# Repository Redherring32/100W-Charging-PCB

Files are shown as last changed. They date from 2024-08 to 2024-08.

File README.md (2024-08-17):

# 100W-Charging-PCB
100W USB C PD Lithium Ion charging PCB based on the TPS25750D and BQ25713

This PCB is spec'd for 20V 5A USB C PD charging of a 1S configuration of Lithium Ion cells, it is suitable for dropping into a variety of battery powered projects that may be a bit more power hungry or where faster charging may be desired.
Within this repository you can find everything to build this PCB, as well as source design files for it should you need to repurpose it for a different form factor or design.

# PCB SPECS:
* 4 layers
* 38.5x38.5mm
* filled vias (VIPPO) is recommended for assembly reasons due to via in pad

Render

## LICENSE:
Licensed under
the TAPR Open hardware license (www.tapr.org/OHL)

©Redherring32 2024

## DISCLAIMER:

Lithium Ion Batteries are DANGEROUS, they should not be handled if you do not know what you are doing.
I offer this with no warranty, express or implied, and I am NOT responsible for anything that may happen as a result of misuse of this PCB.
You have been warned.

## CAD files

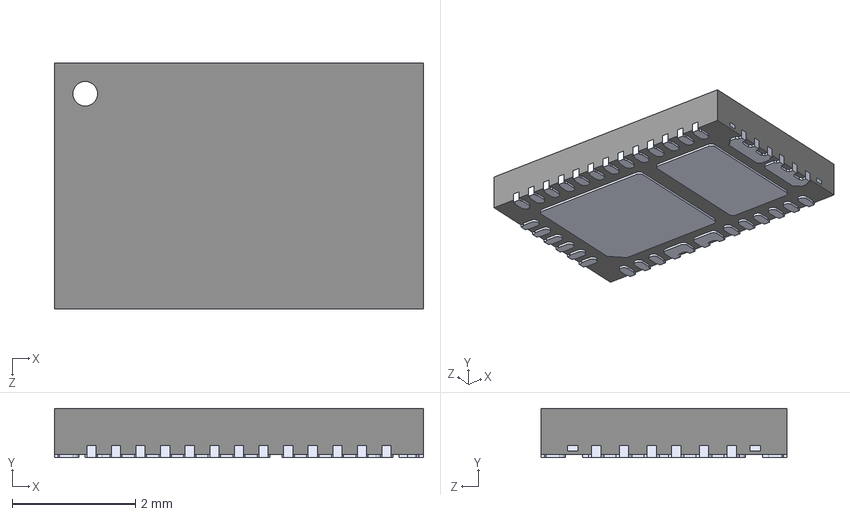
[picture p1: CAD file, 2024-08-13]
3D/TPS25750DRJKR.STEP
6.00 x 0.8 x 4.00 mm

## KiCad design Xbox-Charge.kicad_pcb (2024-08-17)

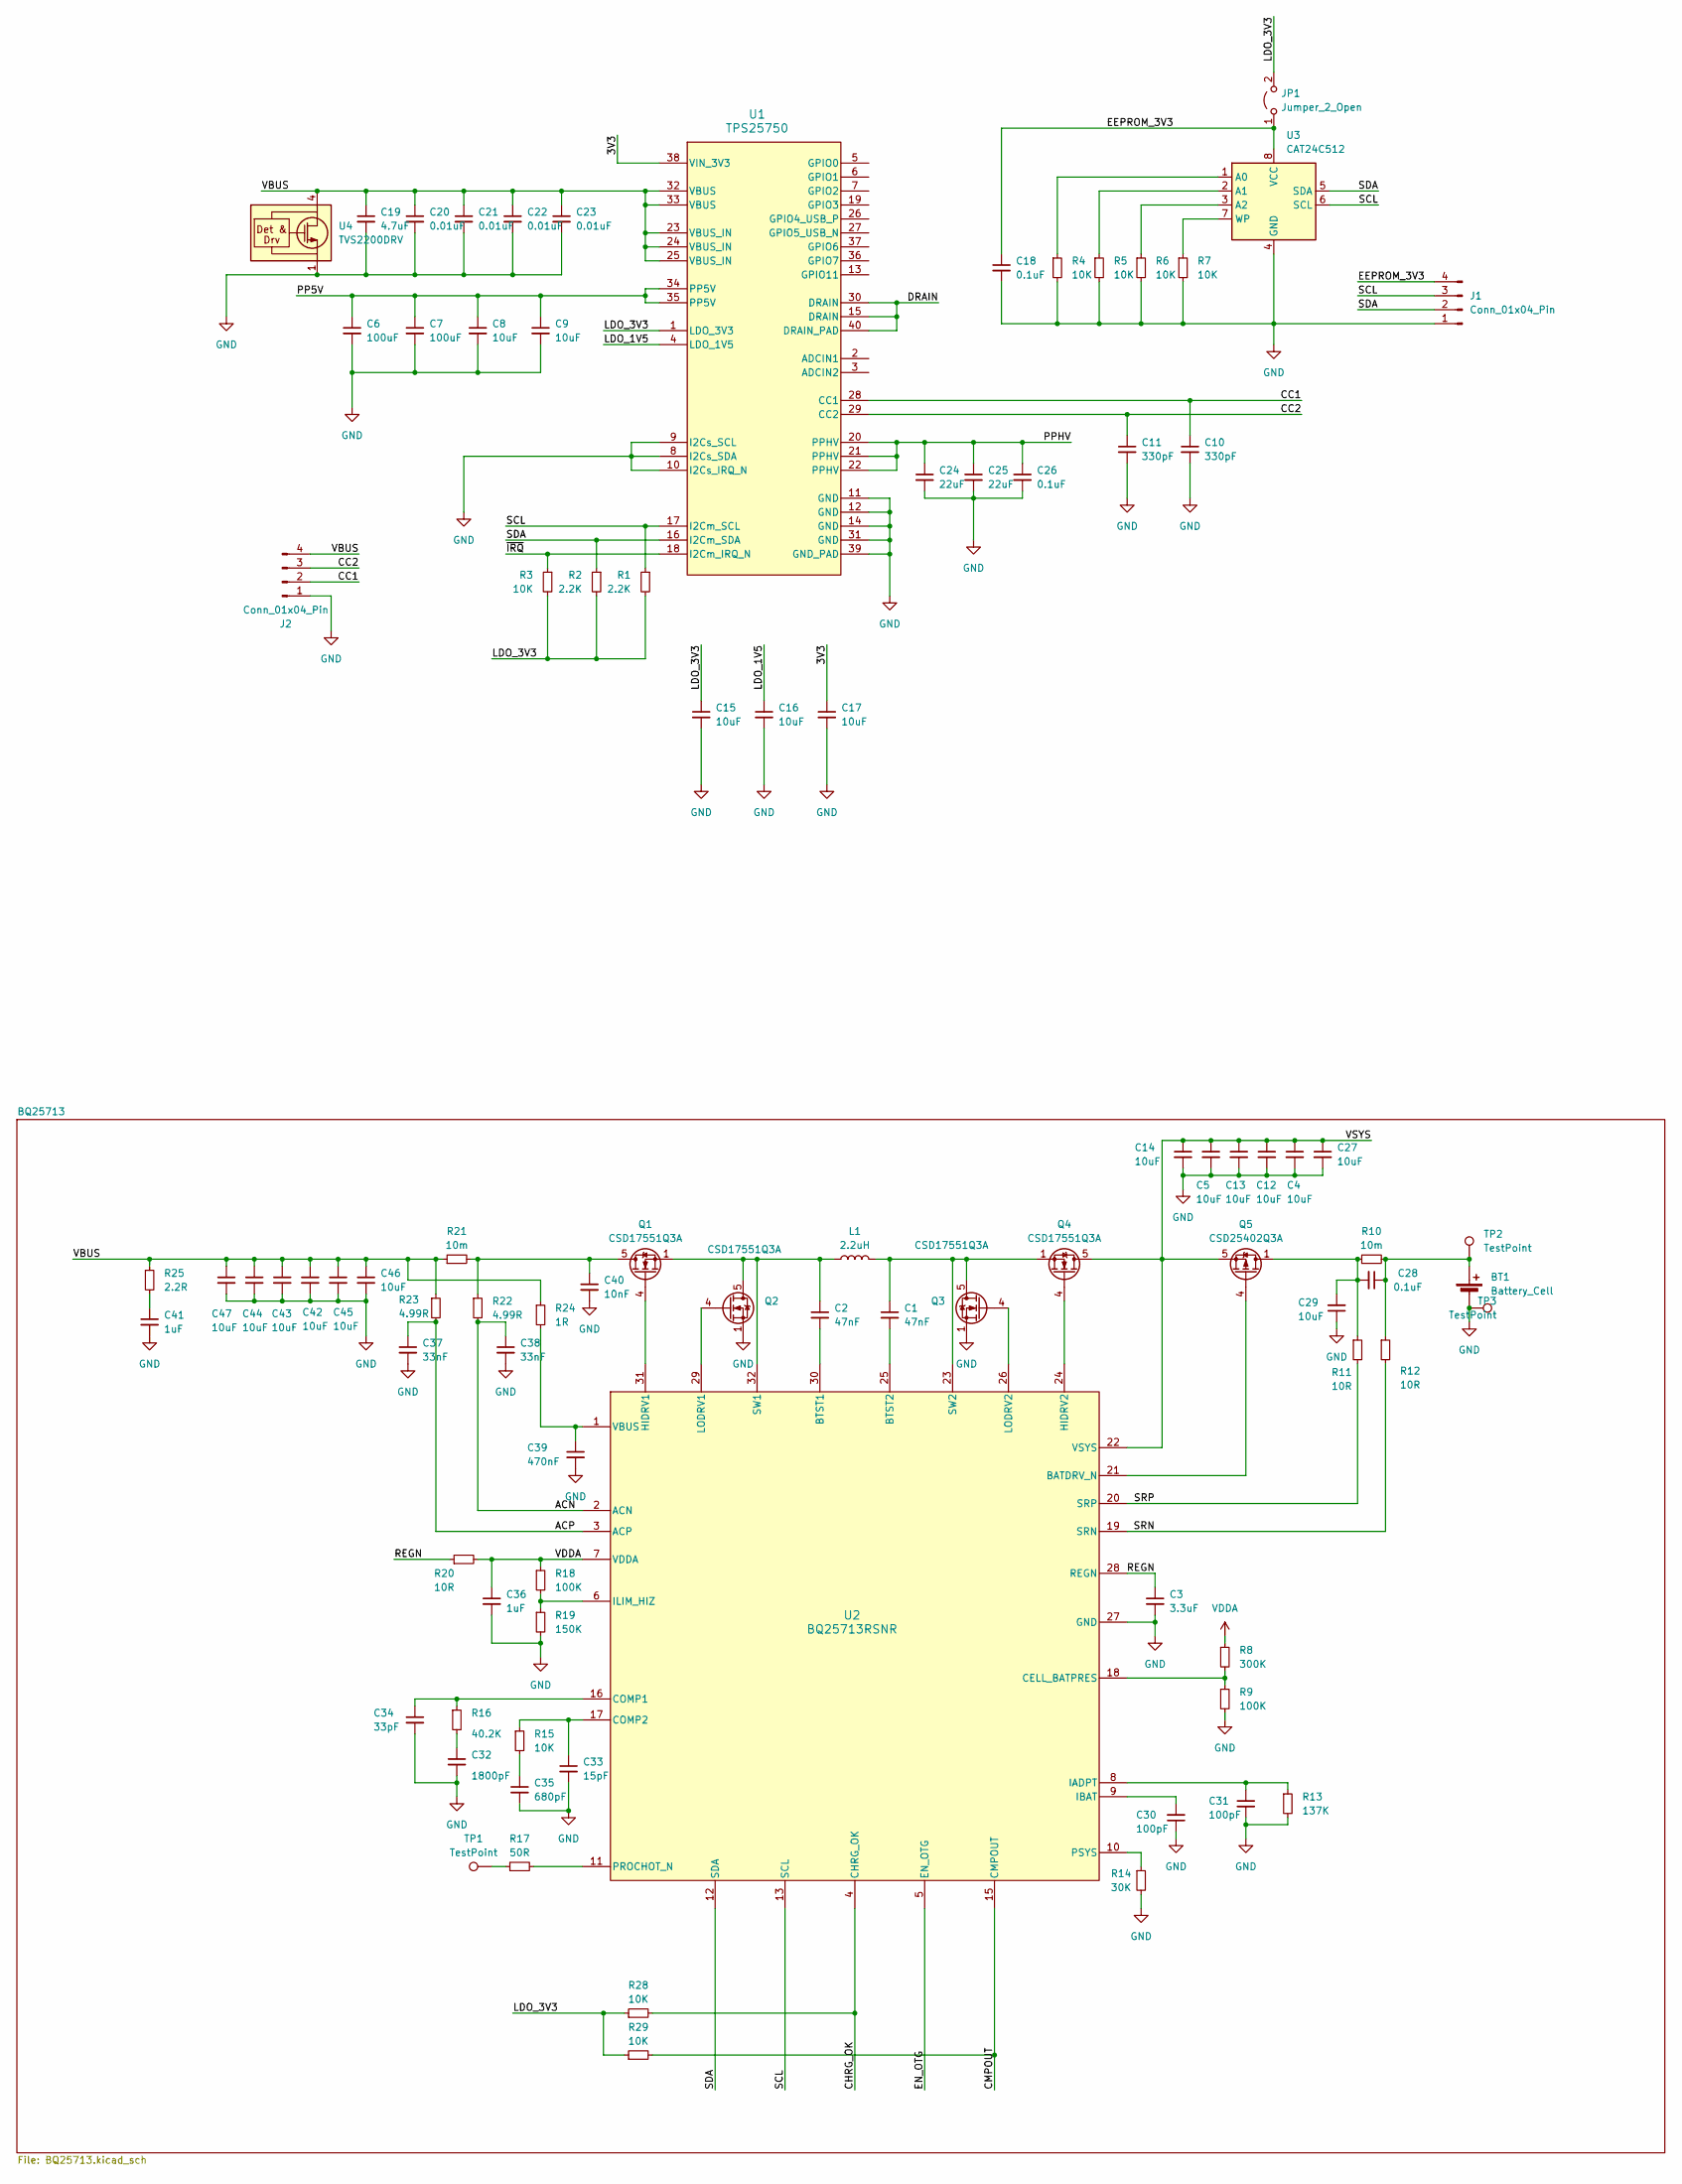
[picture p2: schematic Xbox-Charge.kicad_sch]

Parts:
BT1: Battery_Cell
C1, C2: 47nF; C_0603_1608Metric
C3: 3.3uF; C_0603_1608Metric
C4, C5, C12, C13, C14, C27, C42, C43, C44, C45, C46, C47: 10uF; C_0805_2012Metric
C6, C7: 100uF; C_1210_3225Metric
C8, C9, C29: 10uF; C_0603_1608Metric
C10, C11: 330pF; C_0201_0603Metric
C15, C16, C17: 10uF; C_0402_1005Metric
C18, C26: 0.1uF; C_0402_1005Metric
C19: 4.7uF; C_0805_2012Metric
C20, C21, C22, C23: 0.01uF; C_0402_1005Metric
C24, C25: 22uF; C_0805_2012Metric
C28: 0.1uF; C_0603_1608Metric
C30, C31: 100pF; C_0603_1608Metric
C32: 1800pF; C_0402_1005Metric
C33: 15pF; C_0402_1005Metric
C34: 33pF; C_0402_1005Metric
C35: 680pF; C_0402_1005Metric
C36: 1uF; C_0402_1005Metric
C37, C38: 33nF; C_0603_1608Metric
C39: 470nF; C_0805_2012Metric
C40: 10nF; C_0402_1005Metric
C41: 1uF
J1: Conn_01x04_Pin; PROG
J2: Conn_01x04_Pin; VBUS PADS
JP1: Jumper_2_Open; SolderJumper-2_P1.3mm_Open_RoundedPad1.0x1.5mm
L1: 2.2uH; L_Chilisin_BMRx00060630
Q1, Q2, Q3, Q4: CSD17551Q3A; VSON-8_3.3x3.3mm_P0.65mm_NexFET
Q5: CSD25402Q3A; VSON-8_3.3x3.3mm_P0.65mm_NexFET
R1, R2: 2.2K; R_0402_1005Metric
R3, R4, R5, R6, R7, R15, R28, R29: 10K; R_0402_1005Metric
R8: 300K; R_0402_1005Metric
R9, R18: 100K; R_0402_1005Metric
R10, R21: 10m; R_1206_3216Metric
R11, R12: 10R; R_0603_1608Metric
R13: 137K; R_0603_1608Metric
R14: 30K; R_0603_1608Metric
R16: 40.2K; R_0402_1005Metric
R17: 50R
R19: 150K; R_0402_1005Metric
R20: 10R; R_0402_1005Metric
R22, R23: 4.99R; R_0603_1608Metric
R24: 1R; R_0805_2012Metric
R25: 2.2R
TP1: TestPoint
TP2, TP3: TestPoint; TestPoint_Pad_3.0x3.0mm
U1: TPS25750; TPS25750D
U2: BQ25713RSNR; Texas_RSN_WQFN-32-1EP_4x4mm_P0.4mm_EP2.8x2.8mm
U3: CAT24C512; SOIC-8_3.9x4.9mm_P1.27mm
U4: TVS2200DRV; WSON-6-1EP_2x2mm_P0.65mm_EP1x1.6mm

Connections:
/3V3: C17.1, U1.38 (VIN_3V3)
/ACN: C38.1, R22.2, U2.2 (ACN)
/ACP: C37.1, R23.2, U2.3 (ACP)
/CC1: C10.1, J2.2, U1.28 (CC1)
/CC2: C11.1, J2.3, U1.29 (CC2)
/CHRG_OK: R28.2, U2.4 (CHRG_OK)
/CMPOUT: R29.2, U2.15 (CMPOUT)
/DRAIN: U1.15 (DRAIN), U1.30 (DRAIN), U1.40 (DRAIN_PAD)
/EEPROM_3V3: C18.1, J1.4, JP1.1 (A), U3.8 (VCC)
/EN_OTG: U2.5 (EN_OTG)
/LDO_1V5: C16.1, U1.4 (LDO_1V5)
/LDO_3V3: C15.1, JP1.2 (B), R1.2, R2.2, R3.2, R28.1, R29.1, U1.1 (LDO_3V3)
/PP5V: C6.1, C7.1, C8.1, C9.1, U1.34 (PP5V), U1.35 (PP5V)
/PPHV: C24.1, C25.1, C26.1, U1.20 (PPHV), U1.21 (PPHV), U1.22 (PPHV)
/REGN: C3.1, R20.1, U2.28 (REGN)
/SCL: J1.3, R1.1, U1.17 (I2Cm_SCL), U2.13 (SCL), U3.6 (SCL)
/SDA: J1.2, R2.1, U1.16 (I2Cm_SDA), U2.12 (SDA), U3.5 (SDA)
/SRN: R12.2, U2.19 (SRN)
/SRP: R11.2, U2.20 (SRP)
/VBUS: C19.1, C20.1, C21.1, C22.1, C23.1, C42.1, C43.1, C44.1, C45.1, C46.1, C47.1, J2.4, R21.1, R23.1, R24.1, R25.1, U1.23 (VBUS_IN), U1.24 (VBUS_IN), U1.25 (VBUS_IN), U1.32 (VBUS), U1.33 (VBUS), U4.4 (IN), U4.5 (IN), U4.6 (IN)
/VSYS: C4.1, C5.1, C12.1, C13.1, C14.1, C27.1, Q4.5 (D), Q5.5 (S), U2.22 (VSYS)
/~IRQ: R3.1, U1.18 (I2Cm_IRQ_N)
GND: BT1.2 (-), C3.2, C4.2, C5.2, C6.2, C7.2, C8.2, C9.2, C10.2, C11.2, C12.2, C13.2, C14.2, C15.2, C16.2, C17.2, C18.2, C19.2, C20.2, C21.2, C22.2, C23.2, C24.2, C25.2, C26.2, C27.2, C29.1, C30.1, C31.2, C32.2, C33.2, C34.2, C35.2, C36.2, C37.2, C38.2, C39.2, C40.2, C41.2, C42.2, C43.2, C44.2, C45.2, C46.2, C47.2, J1.1, J2.1, Q2.1 (S), Q2.2 (S), Q2.3 (S), Q3.1 (S), Q3.2 (S), Q3.3 (S), R4.2, R5.2, R6.2, R7.2, R9.2, R13.2, R14.2, R19.2, TP3.1, U1.8 (I2Cs_SDA), U1.9 (I2Cs_SCL), U1.10 (I2Cs_IRQ_N), U1.11 (GND), U1.12 (GND), U1.14 (GND), U1.31 (GND), U1.39 (GND_PAD), U2.27 (GND), U2.33 (PAD), U3.4 (GND), U4.1 (GND), U4.2 (GND), U4.3 (GND), U4.7 (GND)
unnamed: BT1.1 (+), C28.1, R10.2, R12.1, TP2.1
unnamed: C28.2, C29.2, Q5.1 (D), Q5.2 (D), Q5.3 (D), R10.1, R11.1
unnamed: C32.1, R16.2
unnamed: C35.1, R15.2
unnamed: C41.1, R25.2
unnamed: C40.1, Q1.5 (D), R21.2, R22.1
unnamed: Q1.4 (G), U2.31 (HIDRV1)
unnamed: C2.1, L1.1, Q1.1 (S), Q1.2 (S), Q1.3 (S), Q2.5 (D), U2.32 (SW1)
unnamed: Q2.4 (G), U2.29 (LODRV1)
unnamed: C1.1, L1.2, Q3.5 (D), Q4.1 (S), Q4.2 (S), Q4.3 (S), U2.23 (SW2)
unnamed: Q3.4 (G), U2.26 (LODRV2)
unnamed: Q4.4 (G), U2.24 (HIDRV2)
unnamed: Q5.4 (G), U2.21 (BATDRV_N)
unnamed: R17.1, TP1.1
unnamed: C2.2, U2.30 (BTST1)
unnamed: C1.2, U2.25 (BTST2)
unnamed: R8.2, R9.1, U2.18 (CELL_BATPRES)
unnamed: C34.1, R16.1, U2.16 (COMP1)
unnamed: C33.1, R15.1, U2.17 (COMP2)
unnamed: C31.1, R13.1, U2.8 (IADPT)
unnamed: C30.2, U2.9 (IBAT)
unnamed: R18.2, R19.1, U2.6 (ILIM_HIZ)
unnamed: R17.2, U2.11 (PROCHOT_N)
unnamed: R14.1, U2.10 (PSYS)
unnamed: C39.1, R24.2, U2.1 (VBUS)
unnamed: R4.1, U3.1 (A0)
unnamed: R5.1, U3.2 (A1)
unnamed: R6.1, U3.3 (A2)
unnamed: R7.1, U3.7 (WP)
VDDA: C36.1, R8.1, R18.1, R20.2, U2.7 (VDDA)

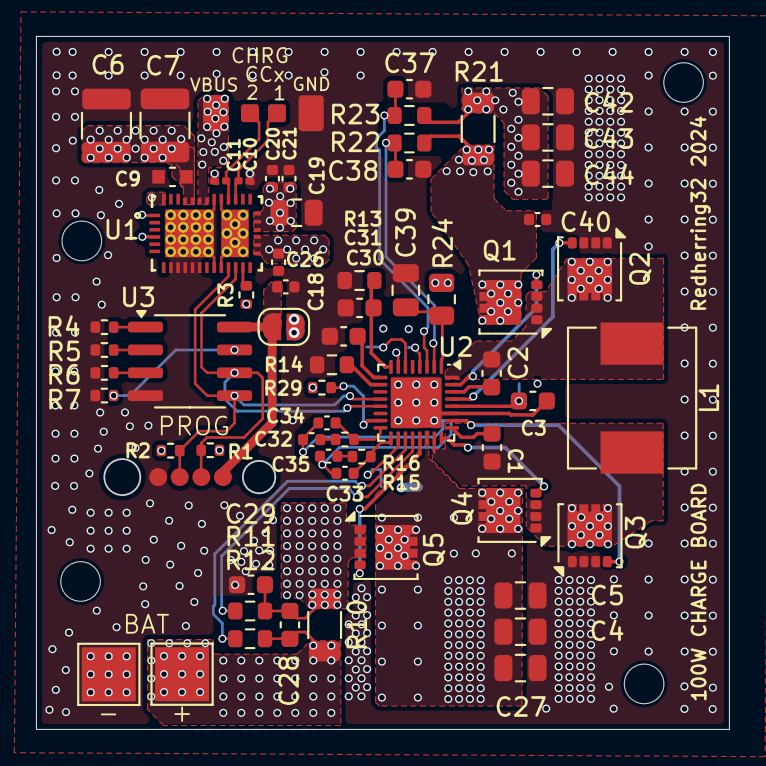
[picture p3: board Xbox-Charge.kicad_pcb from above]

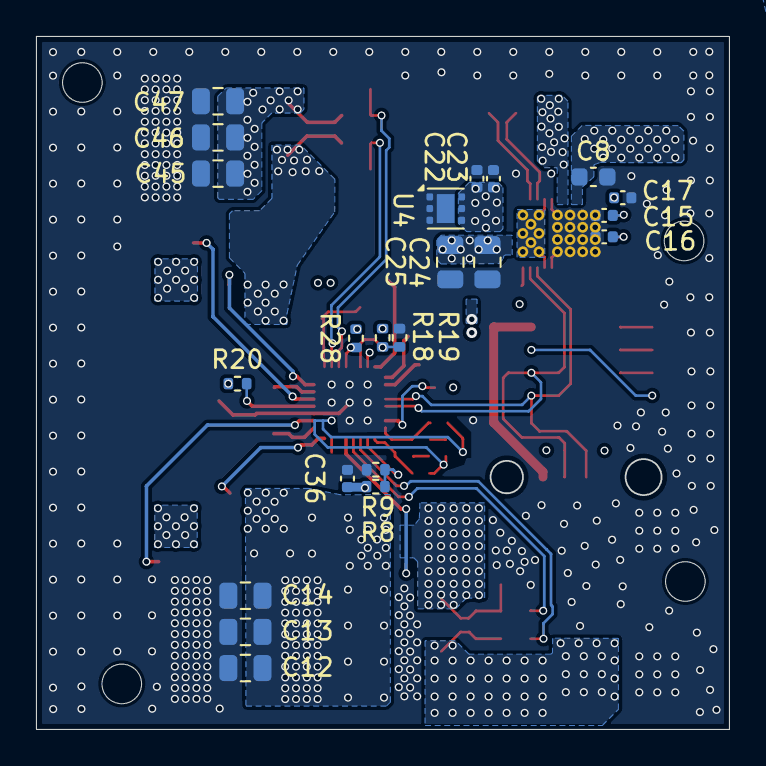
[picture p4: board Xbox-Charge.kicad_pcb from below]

Board: 13 copper layers, 38.5 x 38.5 mm, 86 parts (22 on the bottom side), 49 nets.

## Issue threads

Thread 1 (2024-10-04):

Kicad version is in the future!

Electro-resonance, 2024-10-04:
Hi, Looks very well designed!

I notice that the KiCAD version is strange:
	(version 20240716)
	(generator "eeschema")
	(generator_version "8.99")
	(uuid "14746920-3a54-4dfc-8a29-611d4cb40dcd")

Current released KiCad is 8.05, and 8.99 is rejected by the release versions of kicad.

IcyLetters, 2024-10-04:
8.99 is a nightly build and can be found here: [Kicad Nightly](https://downloads.kicad.org/kicad/windows/explore/nightlies)

Redherring32, 2024-10-04:
Yeah it's made with the 8.99 nightly version of Kicad. I probably shouldn't
be using nightly for stuff I'm open sourcing, but I love trying out the new
features so darn much. :)

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

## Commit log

2024-08-13 Add files and LICENSE
    [TPS25750DRJKR.STEP, Xbox-Charge.kicad_pcb, Xbox-Charge.kicad_sch]
2024-08-17 Update README.md
    Add PCB specs and fix typos.
2024-08-17 Cleaned up schematic and split BQ25713 circuit off to a second sheet
    [BQ25713.kicad_sch, Xbox-Charge.kicad_pcb, Xbox-Charge.kicad_sch]
